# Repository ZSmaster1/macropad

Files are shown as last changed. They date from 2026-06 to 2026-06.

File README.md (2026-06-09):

# Macropad

This macropad has 9 keys, an OLED display, a rotary encoder, and 20 individually adressable LEDs for an underglow effect.

## Features
* Two piece PLA case (no screws or heatset inserts necessary!)
* 128x32 OLED display
* EC11 rotary encoder
* 9 keys arranged in a 3x3 matrix
* 20 SK6812MINI-E indvidually adressable LEDs for underglow effects
* Supports QMK, KMK, and more

## Cad Model
The PCB gets sandwiched in between the main body and the bottom piece. The PCB can be glued using the 4 corners onto the main body or foam or some kind of riser can be placed on the protruding columns on the bottom plate. When the bottom plate is glued to the main body the column will snugly fix the PCB in place. This allows the case to stay slim and compact while still allowing the underglow effect to take place.

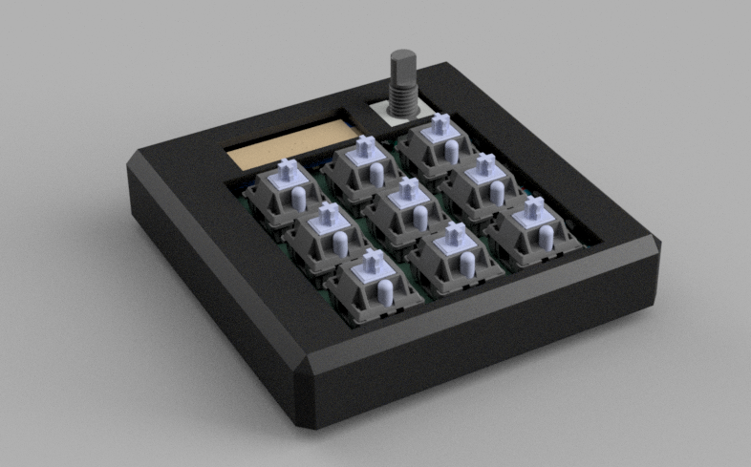
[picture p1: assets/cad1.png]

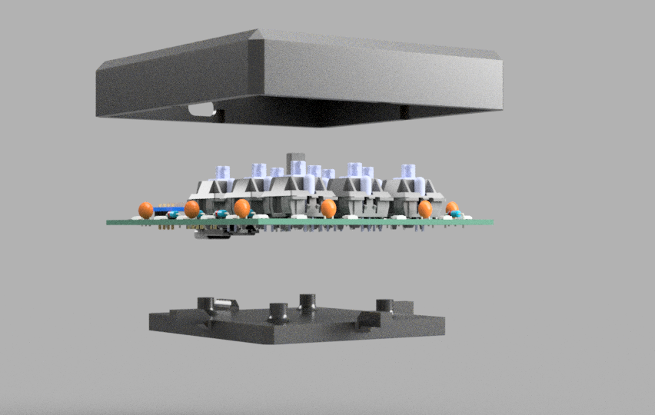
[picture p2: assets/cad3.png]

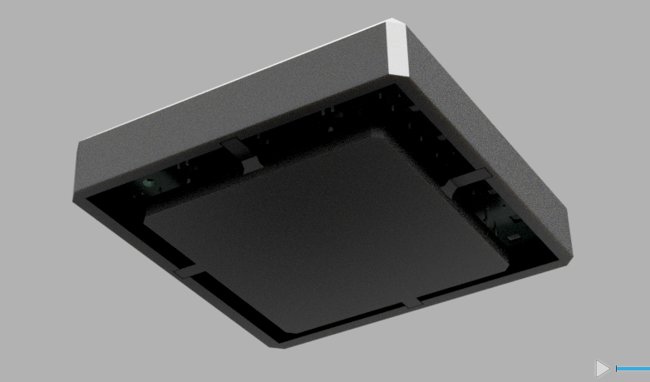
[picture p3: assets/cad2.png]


Made in Fusion 360. Make sure the macropad works outside the case before assembling the case since it will be very hard to take it apart.

## Schematic + PCB
The PCB was made in KiCad, it incorporates 2 layers, a ground plane, and vias.

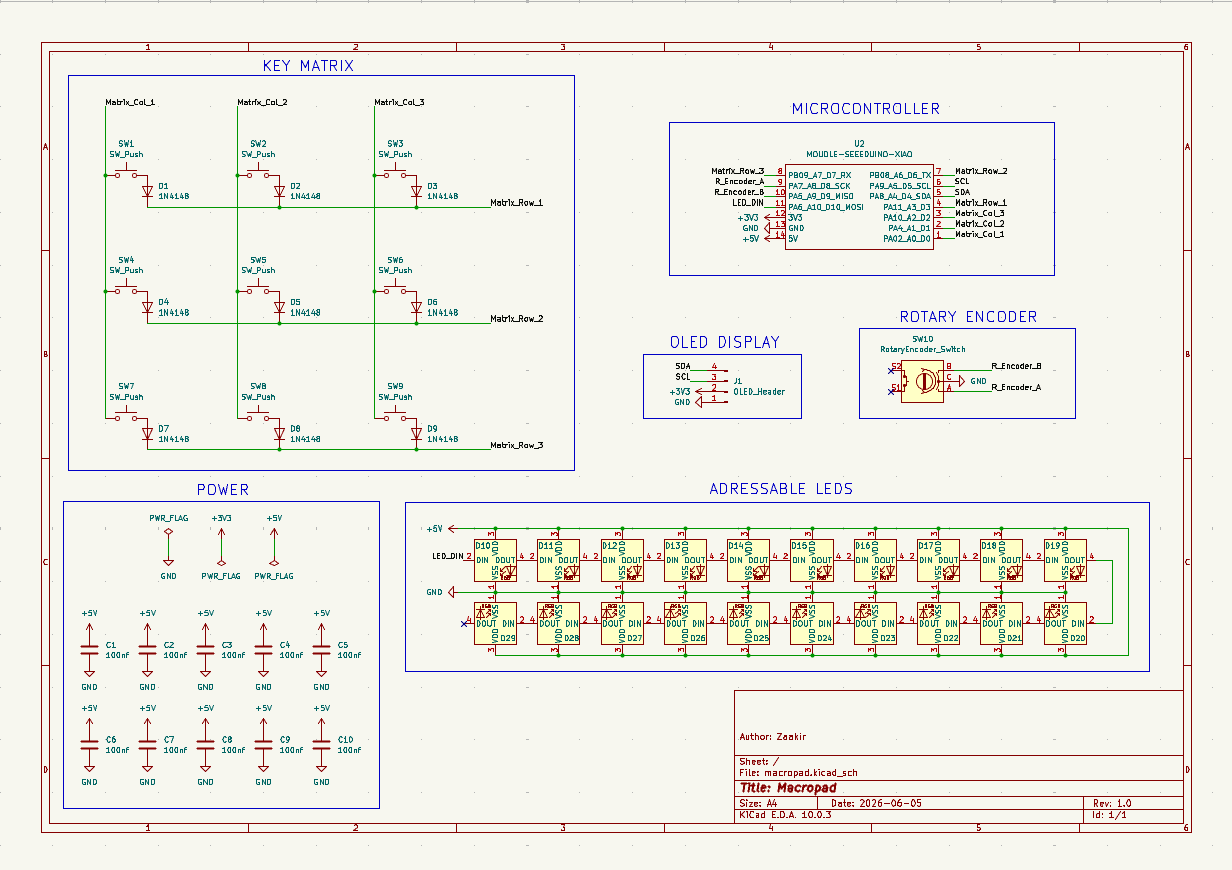
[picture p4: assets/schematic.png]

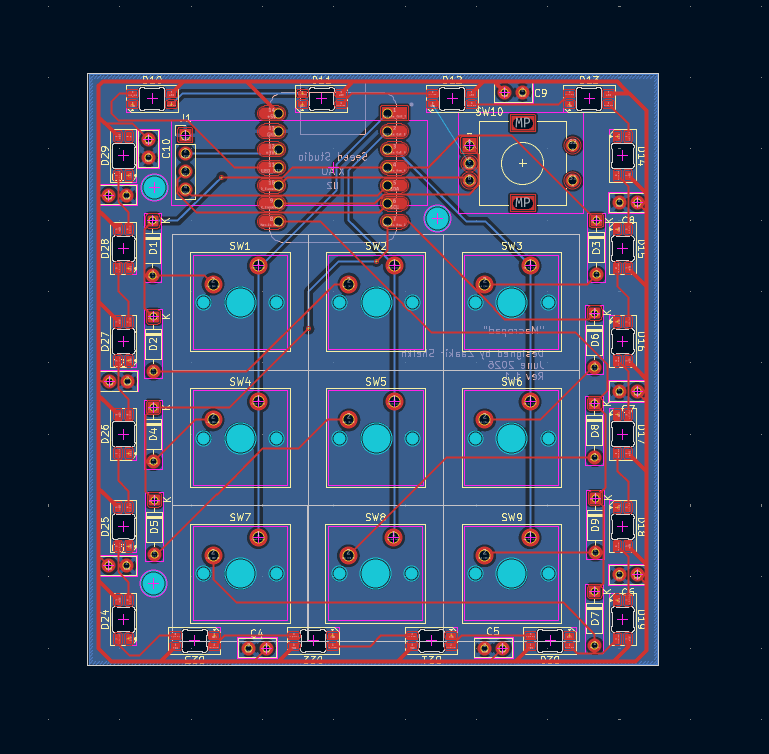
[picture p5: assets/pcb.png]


## Firmware
Currently the firmware is designed to use KMK and circuitpython. However in the future I would like to upgrade to QMK due to its gui configuration interface and more advanced features.

## BOM
Everyting you need to make this macropad:

| Part | Quantity | Optional |
| --- | --- | --- |
| Cherry MX switches | 9 |
| DSA keycaps | 9 |
| 1N4148 DO-35 diode | 9 |
| SK6812MINI-E LED | 20 |
| 0.91" 128x32 i2c OLED Display | 1 |
| EC11 Rotary Encoder | 1 |
| XIAO RP2040 microcontroller | 1 |
| PCB | 1 |
| Case - top | 1 |
| Case - bottom | 1 |
| 100nf through-hole capacitor | 10 | yes

Right now the capacitors were added into the PCB just in case there are any issues with voltage drops due to the amount of LEDs.

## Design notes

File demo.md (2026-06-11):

Interactive CAD Model: [3D Viewer](https://3dviewer.net/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)

Interactive PCB: [KiCanvas](https://kicanvas.org/?repo=https%3A%2F%2Fgithub.com%2FZSmaster1%2Fmacropad%2Ftree%2Fmain%2Fpcb)

Images: [See ReadMe](https://github.com/ZSmaster1/macropad/blob/main/README.md)

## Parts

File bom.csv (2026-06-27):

Part | Quantity | Optional
Cherry MX switches | 9 | no
DSA keycaps | 9 | no
1N4148 DO-35 diode | 9 | no
SK6812MINI-E LED | 20 | no
0.91" 128x32 i2c OLED Display | 1 | no
EC11 Rotary Encoder | 1 | no
XIAO RP2040 microcontroller | 1 | no
PCB | 1 | no
Case - top | 1 | no
Case - bottom | 1 | no
100nf through-hole capacitor | 10 | yes

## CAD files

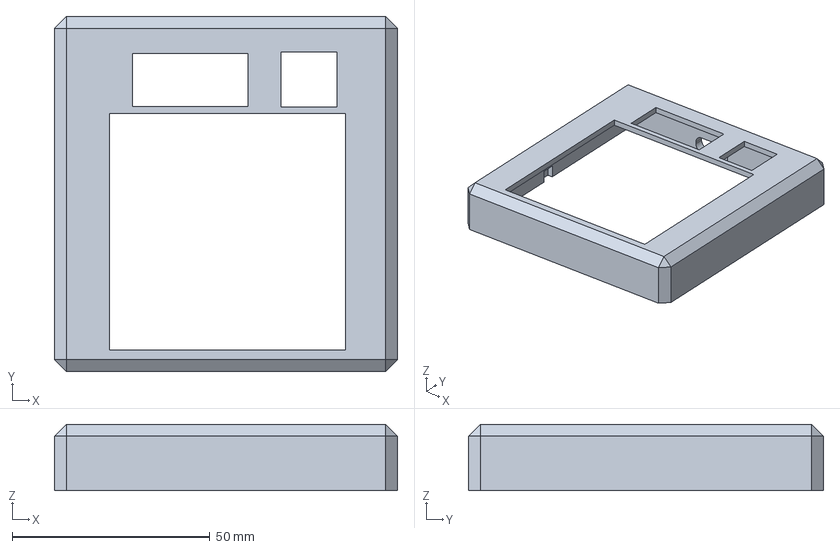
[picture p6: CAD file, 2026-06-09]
production/main body.step
86.8 x 89.8 x 16.8 mm

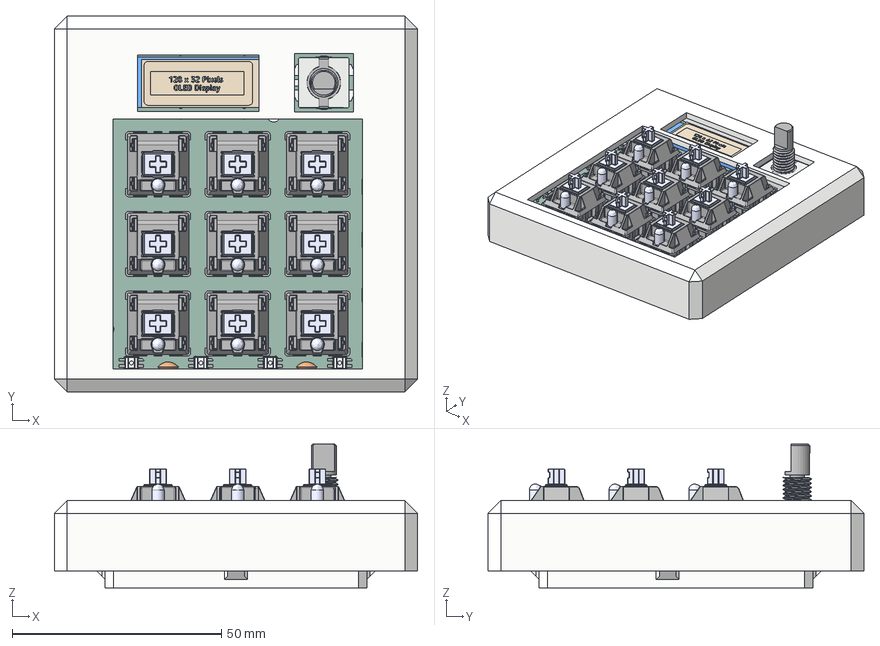
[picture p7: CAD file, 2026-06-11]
cad/macropad_rev1.step
86.8 x 89.8 x 34.3 mm
D_DO-35_SOD27_P7.62mm_Horizontal_1 x 9
Pin1 x 20
Pin2 x 20
Pin3 x 20
Pin4 x 20
C_Disc_D50mm_W25mm_P250mm x 10
PinHeader_1x04_P254mm_Vertical
macropad_PCB
MX Öá °´¼ü¡ä_¨¹ ___¡§1 x 9
MX Öá ÖáÌå¨¢¨¬ _¡§¡é¡§__ x 9
MXÖá ÎÞÃ±LEDLEDLED x 9
MXÖá ÖáÌå µ×²¿ ¦Ì¡ Á2__Ä¬ÈÏ_¨¢2____¨¨_ x 9
Õë½Å___Ä¬ÈÏ__¨¨ _ x 9
Ðý×ª±àÂëÆ÷
type-c v2
smd_button v3
DOUT
DIN
VSS
VDD
smd_button v3(Mirror)
Board_001
0603 Capacitor_001
0603 Capacitor_002
0603 Capacitor_003
0603 Capacitor_004
0603 Capacitor_005
0603 Capacitor_006
0603 Capacitor_007
0603 Capacitor_008
0603 Resistor_001
0603 Resistor_002
0603 Resistor_003
0603 Resistor_004
0603 Resistor_005
Surface Mount Transistor_001
case top
case bottom

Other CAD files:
production/bottom.step

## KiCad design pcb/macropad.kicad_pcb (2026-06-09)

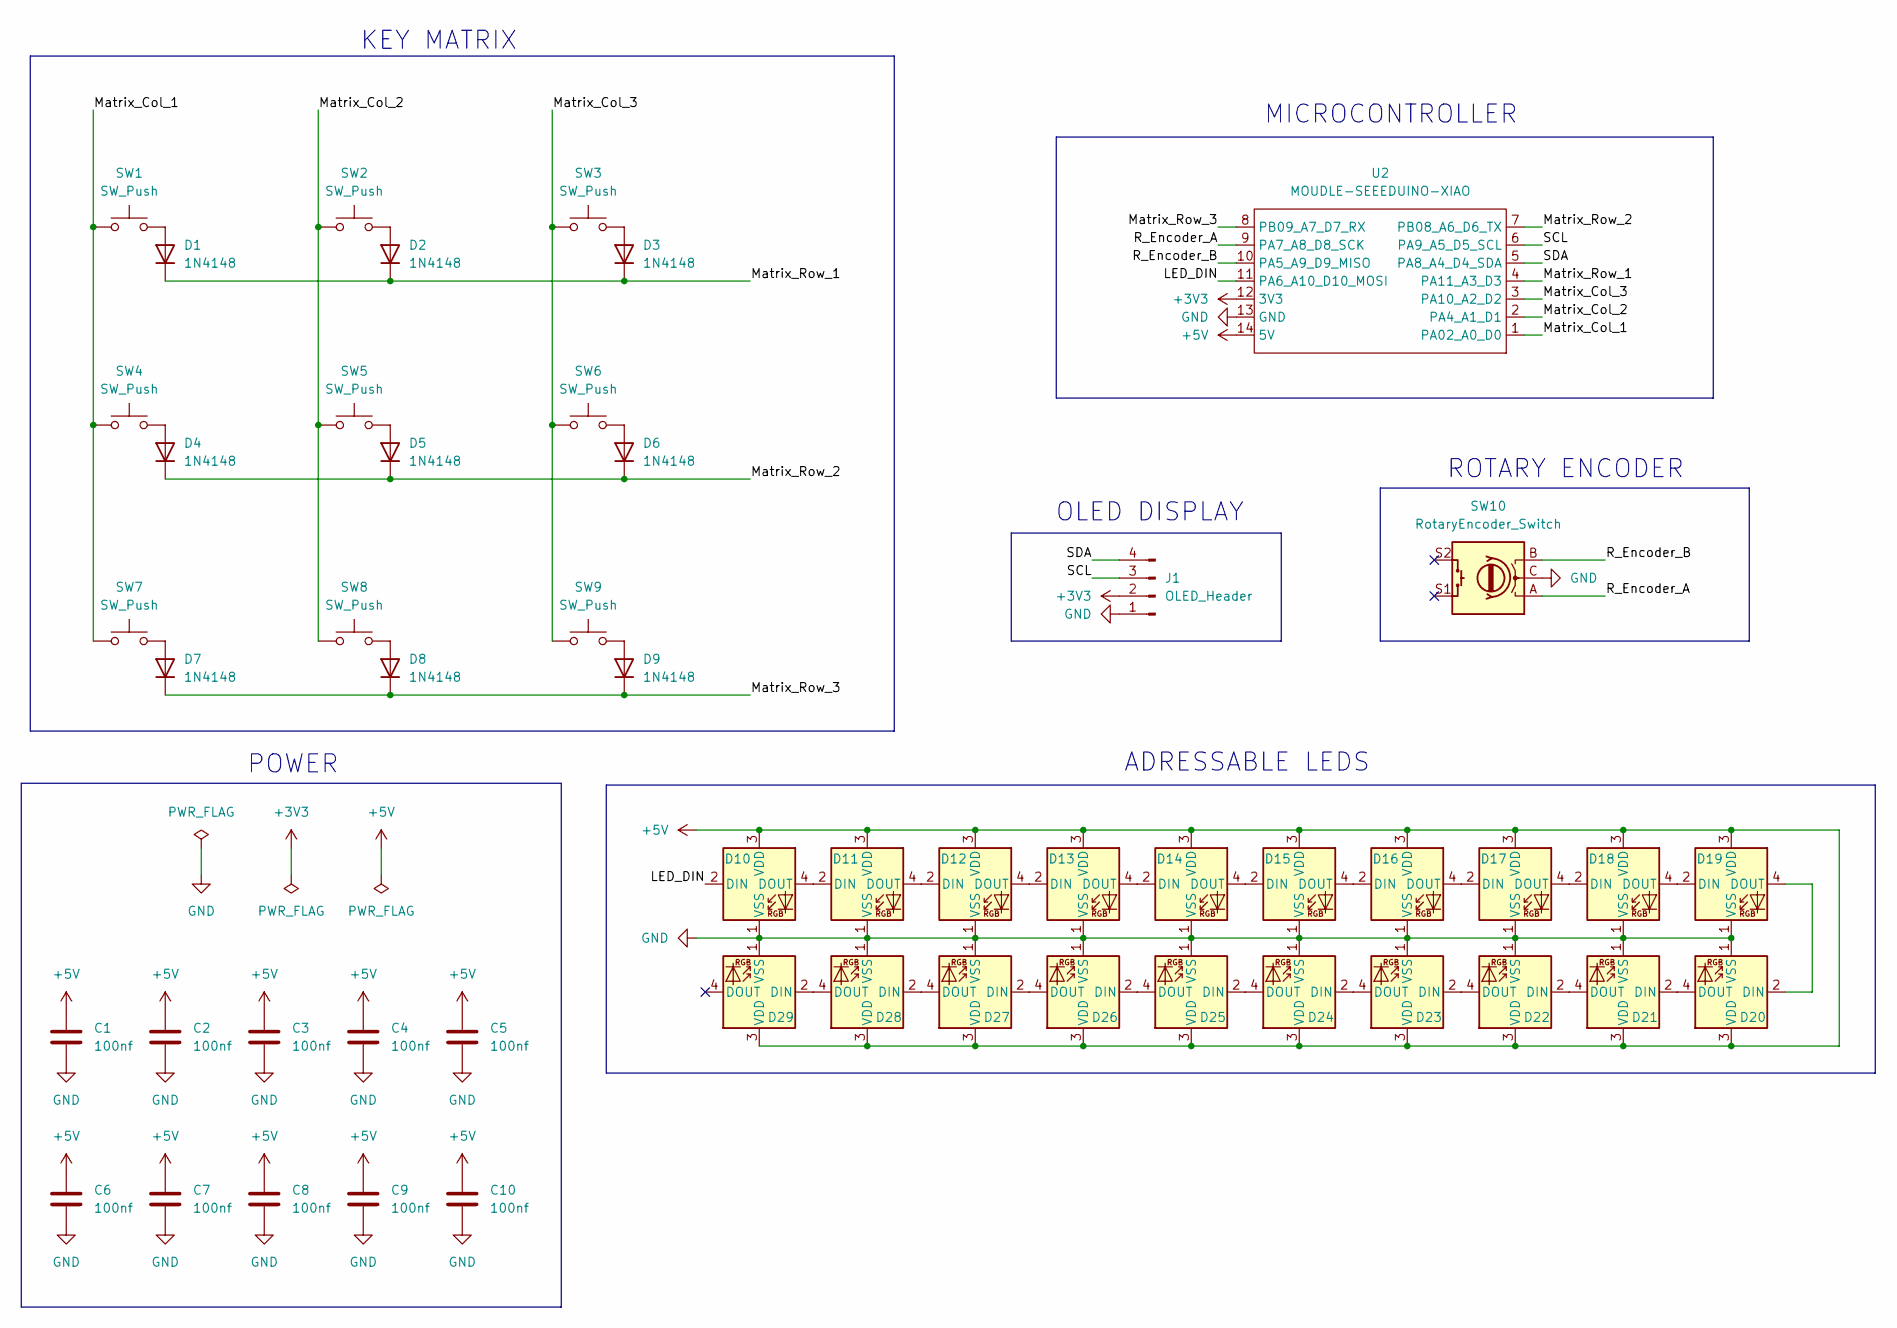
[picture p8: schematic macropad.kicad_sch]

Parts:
C1, C2, C3, C4, C5, C6, C7, C8, C9, C10: 100nf; C_Disc_D5.0mm_W2.5mm_P2.50mm
D1, D2, D3, D4, D5, D6, D7, D8, D9: 1N4148; D_DO-35_SOD27_P7.62mm_Horizontal
D10, D11, D12, D13, D14, D15, D16, D17, D18, D19, D20, D21, D22, D23, D24, D25, D26, D27, D28, D29: SK6812MINI-E; LED_SK6812MINI-E_3.2x2.8mm_P1.5mm_ReverseMount
J1: OLED_Header; PinHeader_1x04_P2.54mm_Vertical
SW1, SW2, SW3, SW4, SW5, SW6, SW7, SW8, SW9: SW_Push; SW_Cherry_MX_1.00u_PCB
SW10: RotaryEncoder_Switch; RotaryEncoder_Alps_EC11E-Switch_Vertical_H20mm
U2: MOUDLE-SEEEDUINO-XIAO; XIAO-Generic-Hybrid-14P-2.54-21X17.8MM

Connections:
+3V3: J1.2, U2.12 (3V3)
+5V: C1.1, C2.1, C3.1, C4.1, C5.1, C6.1, C7.1, C8.1, C9.1, C10.1, D10.3 (VDD), D11.3 (VDD), D12.3 (VDD), D13.3 (VDD), D14.3 (VDD), D15.3 (VDD), D16.3 (VDD), D17.3 (VDD), D18.3 (VDD), D19.3 (VDD), D20.3 (VDD), D21.3 (VDD), D22.3 (VDD), D23.3 (VDD), D24.3 (VDD), D25.3 (VDD), D26.3 (VDD), D27.3 (VDD), D28.3 (VDD), D29.3 (VDD), U2.14 (5V)
/LED_DIN: D10.2 (DIN), U2.11 (PA6_A10_D10_MOSI)
/Matrix_Col_1: SW1.1, SW4.1, SW7.1, U2.1 (PA02_A0_D0)
/Matrix_Col_2: SW2.1, SW5.1, SW8.1, U2.2 (PA4_A1_D1)
/Matrix_Col_3: SW3.1, SW6.1, SW9.1, U2.3 (PA10_A2_D2)
/Matrix_Row_1: D1.1 (K), D2.1 (K), D3.1 (K), U2.4 (PA11_A3_D3)
/Matrix_Row_2: D4.1 (K), D5.1 (K), D6.1 (K), U2.7 (PB08_A6_D6_TX)
/Matrix_Row_3: D7.1 (K), D8.1 (K), D9.1 (K), U2.8 (PB09_A7_D7_RX)
/R_Encoder_A: SW10.A, U2.9 (PA7_A8_D8_SCK)
/R_Encoder_B: SW10.B, U2.10 (PA5_A9_D9_MISO)
/SCL: J1.3, U2.6 (PA9_A5_D5_SCL)
/SDA: J1.4, U2.5 (PA8_A4_D4_SDA)
GND: C1.2, C2.2, C3.2, C4.2, C5.2, C6.2, C7.2, C8.2, C9.2, C10.2, D10.1 (VSS), D11.1 (VSS), D12.1 (VSS), D13.1 (VSS), D14.1 (VSS), D15.1 (VSS), D16.1 (VSS), D17.1 (VSS), D18.1 (VSS), D19.1 (VSS), D20.1 (VSS), D21.1 (VSS), D22.1 (VSS), D23.1 (VSS), D24.1 (VSS), D25.1 (VSS), D26.1 (VSS), D27.1 (VSS), D28.1 (VSS), D29.1 (VSS), J1.1, SW10.C, U2.13 (GND)
unnamed: D1.2 (A), SW1.2
unnamed: D2.2 (A), SW2.2
unnamed: D3.2 (A), SW3.2
unnamed: D4.2 (A), SW4.2
unnamed: D5.2 (A), SW5.2
unnamed: D6.2 (A), SW6.2
unnamed: D7.2 (A), SW7.2
unnamed: D8.2 (A), SW8.2
unnamed: D9.2 (A), SW9.2
unnamed: D10.4 (DOUT), D11.2 (DIN)
unnamed: D11.4 (DOUT), D12.2 (DIN)
unnamed: D12.4 (DOUT), D13.2 (DIN)
unnamed: D13.4 (DOUT), D14.2 (DIN)
unnamed: D14.4 (DOUT), D15.2 (DIN)
unnamed: D15.4 (DOUT), D16.2 (DIN)
unnamed: D16.4 (DOUT), D17.2 (DIN)
unnamed: D17.4 (DOUT), D18.2 (DIN)
unnamed: D18.4 (DOUT), D19.2 (DIN)
unnamed: D19.4 (DOUT), D20.2 (DIN)
unnamed: D20.4 (DOUT), D21.2 (DIN)
unnamed: D21.4 (DOUT), D22.2 (DIN)
unnamed: D22.4 (DOUT), D23.2 (DIN)
unnamed: D23.4 (DOUT), D24.2 (DIN)
unnamed: D24.4 (DOUT), D25.2 (DIN)
unnamed: D25.4 (DOUT), D26.2 (DIN)
unnamed: D26.4 (DOUT), D27.2 (DIN)
unnamed: D27.4 (DOUT), D28.2 (DIN)
unnamed: D28.4 (DOUT), D29.2 (DIN)

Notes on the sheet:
KEY MATRIX
OLED DISPLAY
MICROCONTROLLER
ADRESSABLE LEDS
ROTARY ENCODER
POWER

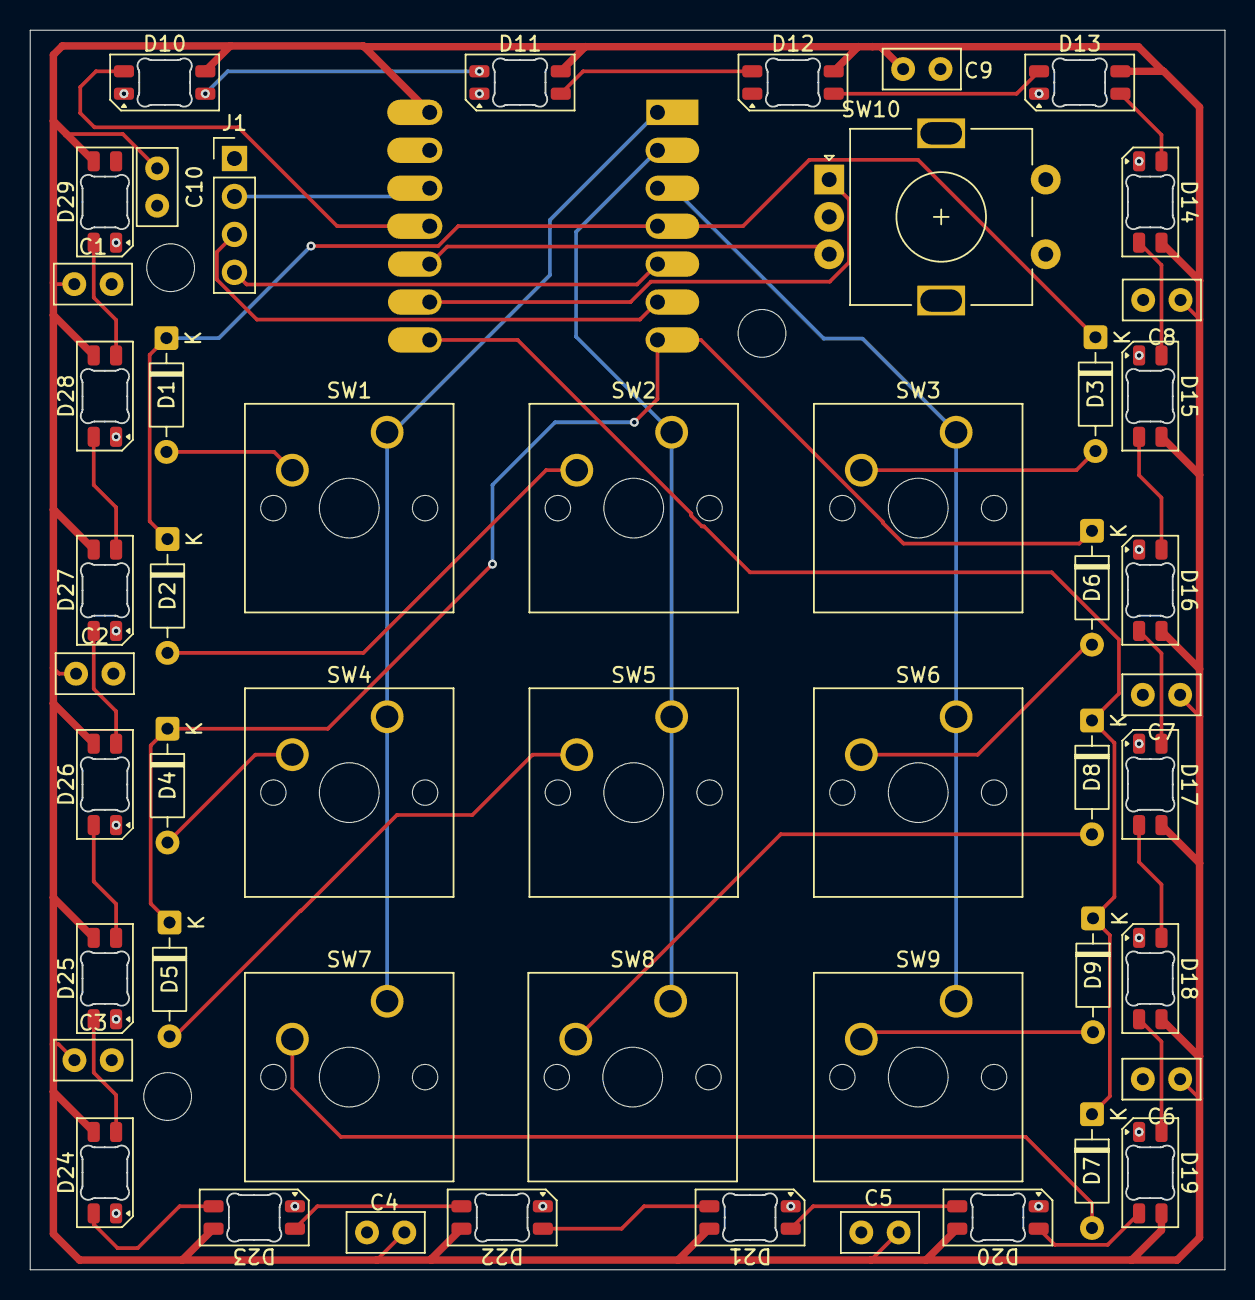
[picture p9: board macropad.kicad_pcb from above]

Board: 2 copper layers, 80.0 x 83.0 mm, 51 parts (1 on the bottom side), 42 nets.

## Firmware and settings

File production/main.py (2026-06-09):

import board
import busio
from kmk.kmk_keyboard import KMKKeyboard
from kmk.keys import KC
from kmk.scanners import DiodeOrientation

from kmk.modules.encoder import EncoderHandler

from kmk.extensions.display import Display, TextEntry
from kmk.extensions.display.ssd1306 import SSD1306

from kmk.extensions.RGB import RGB

keyboard = KMKKeyboard()

keyboard.col_pins = (board.D0, board.D1, board.D2)
keyboard.row_pins = (board.D3, board.D6, board.D7)
keyboard.diode_orientation = DiodeOrientation.COL2ROW

#encoder

encoder_handler = EncoderHandler()

encoder_handler.pins = (
    (board.D8, board.D9),
)

encoder_handler.map = [
    ((KC.VOLD, KC.VOLU, None),),
]

keyboard.modules.append(encoder_handler)

#oled

i2c = busio.I2C(board.SCL, board.SDA)

display = Display(
    display=SSD1306(
        i2c=i2c,
        device_address=0x3C,
    ),
    width=128,
    height=64,
    dim_time=0,
)

display.entries = [
    TextEntry(text="MacroPad"),
]

keyboard.extensions.append(display)

#rgb

rgb = RGB(pixel_pin=board.D10, num_pixels=27)
keyboard.extensions.append(rgb)

#keymap

keyboard.keymap = [
    [KC.RGB_TOG, KC.RGB_HUI, KC.RGB_HUD], 
    [KC.RGB_MODE_SWIRL, KC.N5, KC.N6], 
    [KC.N1, KC.N2, KC.N3] 
]

if __name__ == "__main__":
    keyboard.go()

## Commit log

2026-06-09 Rename main body.step to production/main body.step
    [main body.step]
2026-06-09 Enhance README with project details and specifications
    Expanded README with detailed features, CAD model, schematic, firmware, and BOM.
2026-06-09 Update README with assembly note for macropad
    Added a note about testing the macropad before assembly.
2026-06-11 Add demo.md with links to CAD and PCB models
2026-06-27 Add bill of materials for project components
    [bom.csv]
2026-06-27 Fix formatting of 100nf capacitor entry in bom.csv
2026-06-27 Fix formatting issues in bom.csv
    [bom.csv]
